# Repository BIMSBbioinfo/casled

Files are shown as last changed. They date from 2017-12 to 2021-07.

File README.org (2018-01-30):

* Layout

#+BEGIN_EXAMPLE
/firmware
/pcb
  /footprints
/schematics
  /symbols
#+END_EXAMPLE

* Software

We use the gEDA/gaf suite of tools, most importantly =gschem= for editing schematics and =pcb= for the layout of the circuit boards.

We also use the AVR toolchain to build the firmware binaries and upload them to the micro-controller.

You can get these applications through GNU Guix:

#+BEGIN_SRC bash
guix package -i geda-gaf pcb avr-toolchain@4
#+END_SRC

* Footprints and symbols

The footprints and symbols were downloaded directly from Maxim in the
=bxl= format.  gEDA software does not read the =bxl= format natively,
so it had to be converted to =.sym= (for schematic symbols) and =.fp=
(for PCB footprints).  This can be done with translate2geda [1].

[1]: https://github.com/erichVK5/translate2geda

    java translate2geda max6969awg.bxl

This results in these four files:

    21-0042B_24.fp
    21-0042B_24-L.fp
    21-0042B_24-M.fp
    MAX6969AWG.sym

I created the footprint for the XLamp LEDs from scratch according to the recommendations in the datasheet.

The =.fp= files were moved to =./pcb/footprints= and the =.sym= file to =./pcb/symbols=.

We now only need to tell =gschem= about the symbols and =pcb= about the footprints.  Run =gschem -s gschemrc cas13-led.sch= from the =pcb= directory to evaluate the code in =gschemrc= before opening up the schematic file =cas13-led.scm=.  The =gschemrc= adds the =pcb/symbols= directory to the component library.

To update the PCB after changing the schematics, run =make= from the =pcb= directory.  This runs =gsch2pcb --gnetlist-arg '-lgschemrc' project=; the =--gnetlist-arg= option must be passed to ensure that the custom symbols and footprints are found.

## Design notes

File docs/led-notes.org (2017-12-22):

This is a list of LEDs that we considered for this project before
deciding on the Cree XLamp MLESBL that is still very bright at 50mA.

* SMBB470H-1100 (epitex)
[[file:~/Downloads/SMBB470H-1100.pdf::%25PDF-1.5%0D]]
- wavelength: 470nm
- flux @350mA: 80 mW/sr or 25lm
- flux @100mA: factor 0.3 => 7.5lm

* SMBB490H-1100 (marubeni)
[[file:~/Downloads/SMBB490H-1100.pdf]]
- wavelength: 490nm
- flux @350mA: 68 mW/sr or 70lm
- flux @100mA: factor 0.35 => 24.5lm

* Cree XLamp MLEBLU-A1-0000-000U01 (groups B6+G0)
[[file:~/Downloads/XlampMLE-180564.pdf::%25PDF-1.4]]
- wavelength: 485nm
- flux @150mA: 13.9lm
- flux @100mA: 75% => 10.4lm

* Cree XLamp MLESBL-A1-0000-000U01
- wavelength: 485nm
- flux @50mA: 13.9lm!
https://eu.mouser.com/ProductDetail/Cree-Inc/MLESBL-A1-0000-000U01/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

* Lumiled Luxeon 3535L (L135-B475003500000)
[[file:~/Downloads/DS146-748694.pdf::%25PDF-1.4]]
- wavelength: 469—480nm
- flux @100mA: 11.0lm
- flux @50mA: factor 0.5 => 5.5lm
- cheap!
http://de.futureelectronics.com/de/Technologies/Product.aspx?ProductID=L135B475003500000LUMILEDS1073274&IM=0

* Lumiled Luxeon Rebel (LXML-PE01-0070)
file:~/Downloads/DS68.pdf
- flux @350mA: 76lm
- flux @100mA: unknown! Guess factor 0.2: 15.2lm
- most expensive!
http://de.futureelectronics.com/de/technologies/semiconductors/lighting-solutions/led-emitters/high-power-led-emitters-rev/Seiten/4497244-LXML-PE01-0070.aspx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

* Lumiled Luxeon Rebel (LXML-PB01-0040)
file:~/Downloads/DS68.pdf
- flux @700mA: 41lm 
- flux @100mA: factor 0.3 => 12.3lm

* Lumiled Luxeon Rebel (LXML-PB02)
file:~/Downloads/DS68.pdf
- flux @700mA: 74lm 
- flux @100mA: factor 0.2 => 14.8lm

* Cree XLamp XP-E2 (XPEBBL-L1-0000-00201)
- wavelength: 475nm
- flux @350mA: 43lm
- flux @150mA: factor 0.5 => 21.5lm
- not tested for 100mA or lower!
https://www.digikey.com/product-detail/en/cree-inc/XPEBBL-L1-0000-00201/XPEBBL-L1-0000-00201CT-ND/4111293

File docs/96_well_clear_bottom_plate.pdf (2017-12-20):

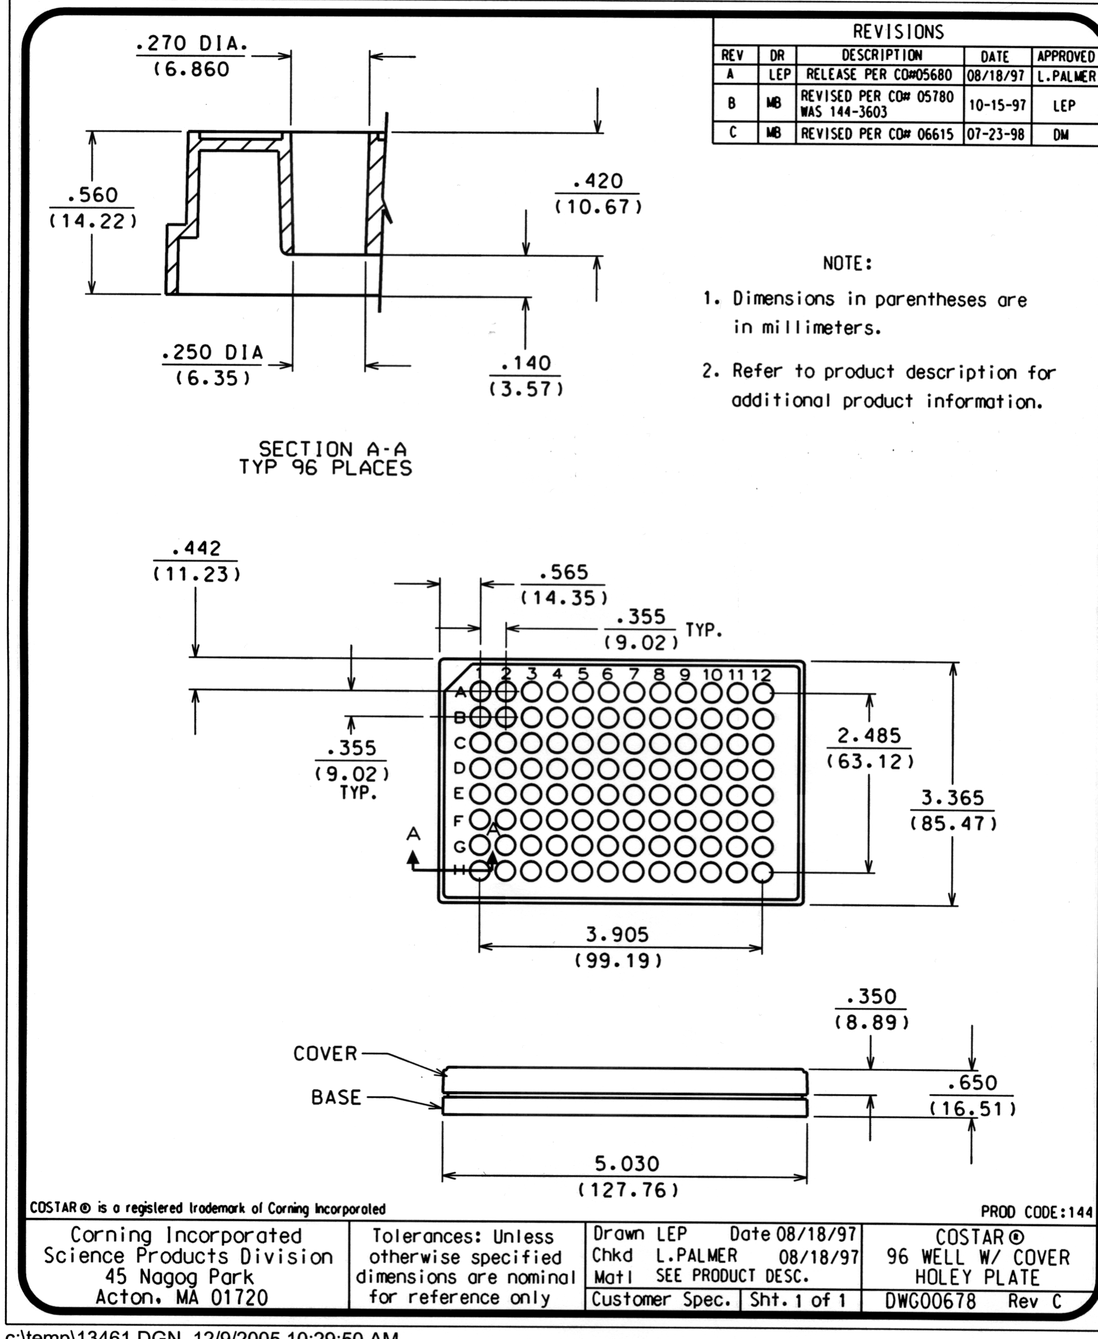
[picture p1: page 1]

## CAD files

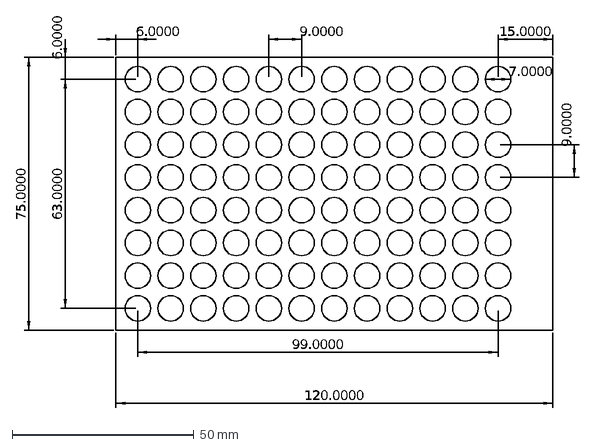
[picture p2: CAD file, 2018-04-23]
enclosure/mask.dxf
7.0000
99.0000
9.0000
6.0000
15.0000
63.0000
120.0000
75.0000

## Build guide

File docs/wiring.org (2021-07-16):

Wiring up the board is a bit challenging.

The board has a grey data cable and a black power cable.  The data
cable has three signals: red, blue, and green.  All other wires should
be tied to GND.

Connect the header with the three signals to the micro controller
board on PORTB.  The green wire should be right next to the cutout,
towards the edge of the board.  Red and blue face inward, towards the
controller chip.

The power cable has three wires:

- yellow/green for GND (at the power supply)
- blue for +5V (get from micro controller board)
- brown for +8V (or +9V if you can stand the heat), from power supply

Attach the micro controller wires to the power supply.

The lab power supply has a resistance change detector.  Disable it in
the “Setup” screen by switching “RRCd” from “YES” to “NO”.

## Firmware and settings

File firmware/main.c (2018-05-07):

#ifndef F_CPU
#warning "F_CPU was not defined, defaulting to 16MHz"
#define F_CPU 16000000UL  // must be unsigned long
#endif
#define BAUD 31250UL

#include <avr/io.h>
#include <util/setbaud.h>
#include <util/delay.h>

/* Time between program steps in milliseconds */
#define INTERVAL 1000.0

/*
Click the speaker and toggle the on-board indicator LEDs to indicate
the passing of time.
*/
#define TICK PORTD ^= 1<<PD7; PORTC++;

/* Pins used for serial interface */
#define DD_SCK    PB7 // clock (blue)
#define DD_MOSI   PB5 // data (red)
#define DDR_SPI   DDRB

/*
"Load enable" is connected to the LE pin of the LED drivers.  The
internal state of the shift registers of the driver chips is pushed to
the LED outputs on a falling edge and held as long as LE is held low
(HOLD).
*/
#define LOAD_PIN PB4 // load enable (green)
#define HOLD (PORTB &= ~(1<<LOAD_PIN))
#define LOAD (PORTB |= (1<<LOAD_PIN))


/*
There are 6 LED driver chips with 16 outputs each, so we need to
transmit 12 bytes over SPI.
*/
#define LED_BYTES 12

#include "progs.h"



#define LEDS 96

/*
Pointers to the current instruction in the program.  This is read and
updated.
*/
uint8_t* P_COUNTER[LEDS];

/*
LED state and counter.

The most significant bit is 0 for OFF and 1 for ON; the remaining bits
encode the remaining time.  When the remaining time is zero we move on
to the next instruction unless the instruction is HALT.
*/
uint8_t LED_STATE[LEDS];

/*
Pointers to LED blink programs.

This array always points to the first instruction of a program.  It is
needed in order to be able to loop back to the beginning of the
program with the LOOP instruction.  The contents of this array are
named according to the identifiers on the well plate (A-H, 1-12).

The order is all messy because the LEDs are not wired up sequentially
and we're fixing a hardware annoyance in software.  Don't judge.
*/

uint8_t* PROGRAMS[LEDS] = {
  G2, H2, E2, F2,
  G1, H1, E1, F1,

  F3, E3, H3, G3,
  F4, E4, H4, G4,

  G6, H6, E6, F6,
  G5, H5, E5, F5,

  F7, E7, H7, G7,
  F8, E8, H8, G8,

  G10, H10, E10, F10,
  G9, H9, E9, F9,

  F11, E11, H11, G11,
  F12, E12, H12, G12,

  B2, A2, D2, C2,
  B1, A1, D1, C1,

  C3, D3, A3, B3,
  C4, D4, A4, B4,

  B6, A6, D6, C6,
  B5, A5, D5, C5,

  C7, D7, A7, B7,
  C8, D8, A8, B8,

  B10, A10, D10, C10,
  B9, A9, D9, C9,

  C11, D11, A11, BROKEN,
  C12, D12, A12, BROKEN
};

/* Initialize SPI interface. */
void spi_init () {
  // Latch, MOSI, and SCK are outputs, all others are inputs
  DDR_SPI = (1<<LOAD_PIN)|(1<<DD_MOSI)|(1<<DD_SCK);
  // Enable SPI as Master, clock rate is fck/128
  //SPCR = (1<<SPE)|(1<<MSTR)|(1<<SPI2X)|(0<<SPR1)|(0<<SPR0);
  SPCR = (1<<SPE)|(1<<MSTR)|(0<<SPI2X)|(1<<SPR1)|(1<<SPR0);
}

/* Send a byte over SPI and wait for completion. */
void spi_transmit (uint8_t data) {
  SPDR = data;
  // Wait for transmission completion
  while (!(SPSR & (1<<SPIF)));
}

/*
Evaluate the current instruction for all LED programs.

This either leads to a delay counter to be decremented or the next
instruction to be selected.
*/
void prog_eval () {
  // LED states to be sent over serial connection.
  uint8_t bytes[LED_BYTES] = {0};

  for (uint8_t i=0; i < LEDS; i++)
    {
      /*
        Are we still waiting for an ON/OFF instruction to be
        completed?
      */
      if (LED_STATE[i] & 0x7F) {
        // Yes, so just count down.
        LED_STATE[i]--;
      } else {
        /*
          Reset and evaluate the next instruction on LOOP.  The first
          instruction cannot be LOOP.
        */
        if (LOOP == *(P_COUNTER[i]))
          P_COUNTER[i] = PROGRAMS[i];

        if (HALT != *(P_COUNTER[i])) {
          // initialize count down
          LED_STATE[i] = *(P_COUNTER[i]);
          // advance program
          P_COUNTER[i]++;
        }
      }

      /* Set LED on or off in byte message array */
      uint8_t new_state = (LED_STATE[i] >> 7);
      if (new_state) {
        // set bit
        bytes[i / 8] |= (1 << (i % 8));
      } else {
        // clear bit
        bytes[i / 8] &= ~(1 << (i % 8));
      }
    }

  /* Transmit new state for all LEDs */
  for (uint8_t n = 0; n < LED_BYTES; n++)
    spi_transmit (bytes[n]);
  LOAD; _delay_ms(10.0); HOLD;
  TICK;
}

void init (void) {
  spi_init ();
  DDRD = 0xFF;  // all outputs (for speaker and "load enable")
  DDRC = 0xFF;  // all outputs
  PORTC = 0x00; // all activity indicator LEDs on

  /* Turn all external LEDs off initially */
  for (uint8_t n = 0; n < LED_BYTES; n++)
    spi_transmit (0x00);
  LOAD; _delay_ms(1000.0); HOLD;

  /* Initialize LED programs and associated state */
  for (uint8_t i = 0; i < LEDS; i++)
    {
      P_COUNTER[i] = PROGRAMS[i];
      LED_STATE[i] = 0x00;
    }
}

int main (void) {
  init ();

  uint8_t p = 0;
  while (p < 40)
    {
      TCCR2 = (1<<FOC2)|(1<<WGM21)|(1<<COM20);
      //TCNT2 = 0;
      _delay_ms(20.0);
      OCR2 = p++;
      TCCR2 |= (1<<CS22)|(1<<CS21)|(1<<CS20);
      _delay_ms(9.0);
    }
  TCCR2 = 0;

  _delay_ms(1000.0);
  while (1) {
    prog_eval ();
    _delay_ms(INTERVAL);
  }

  // This will never happen.
  return 0;
}

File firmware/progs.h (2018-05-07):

#include <avr/io.h>
#include <util/delay.h>

/* LED program instructions */
#define LOOP 0x7F
#define HALT 0xFF

/* Instructions to turn the LED on/off for 1 to 127 units. */
#define LED_ON(n)  ((0x80 | ((n) - 1)))
#define LED_OFF(n) ((0x7F & ((n) - 1)))

/*
NOTE: programs cannot begin with LOOP.  All programs must end with
either LOOP or HALT.
*/

/* This program ensures that the LED stays off. */
uint8_t progOff[] = { LED_OFF(10), LOOP };

/* This program ensures that the LED stays lit. */
uint8_t progOn[]  = { LED_ON(1), HALT };

/* This program lets an LED blink 50/50. */
uint8_t progBlink[] = { LED_ON(1), LED_OFF(1), LOOP };

/* This program lets an LED blink 50/50, but starts in the Off state. */
uint8_t progBlinkOff[] = { LED_OFF(1), LED_ON(1), LOOP };

#define ON_TIME 10
#define OFF_TIME 20

/* Constant blink for Magnet photo dimer */
uint8_t progMagnetBlink[] = { LED_ON(ON_TIME), LED_OFF(OFF_TIME), LOOP };

/* Blink, then lock ON for Magnet photo dimer */
uint8_t progMagnetBlinkLockOn[] = {
  LED_ON(3),   /* 1 */
  LED_OFF(7),
  LED_ON(3),   /* 2 */
  LED_OFF(7),
  LED_ON(3),   /* 3 */
  LED_OFF(7),
  LED_ON(3),   /* 4 */
  LED_OFF(7),
  LED_ON(3),   /* 5 */
  LED_OFF(7),
  LED_ON(3),   /* 6 */
  LED_OFF(7),
  LED_ON(3),   /* 7 */
  LED_OFF(7),
  LED_ON(3),   /* 8 */
  LED_OFF(7),
  LED_ON(3),   /* 9 */
  LED_OFF(7),
  LED_ON(3),   /* 10 */
  LED_OFF(7),
  LED_ON(3),   /* 11 */
  LED_OFF(7),
  LED_ON(3),   /* 12 */
  LED_OFF(7),
  LED_ON(3),   /* 13 */
  LED_OFF(7),
  LED_ON(3),   /* 14 */
  LED_OFF(7),
  LED_ON(3),   /* 15 */
  LED_OFF(7),
  LED_ON(3),   /* 16 */
  LED_OFF(7),
  LED_ON(3),   /* 17 */
  LED_OFF(7),
  LED_ON(3),   /* 18 */
  LED_OFF(7),
  LED_ON(3),   /* 19 */
  LED_OFF(7),
  LED_ON(3),   /* 20 */
  LED_OFF(7),

  LED_ON(120),
  LOOP
};

/* Blink, then lock OFF for Magnet photo dimer */
uint8_t progMagnetBlinkLockOff[] = {
  LED_ON(3),   /* 1 */
  LED_OFF(7),
  LED_ON(3),   /* 2 */
  LED_OFF(7),
  LED_ON(3),   /* 3 */
  LED_OFF(7),
  LED_ON(3),   /* 4 */
  LED_OFF(7),
  LED_ON(3),   /* 5 */
  LED_OFF(7),
  LED_ON(3),   /* 6 */
  LED_OFF(7),
  LED_ON(3),   /* 7 */
  LED_OFF(7),
  LED_ON(3),   /* 8 */
  LED_OFF(7),
  LED_ON(3),   /* 9 */
  LED_OFF(7),
  LED_ON(3),   /* 10 */
  LED_OFF(7),
  LED_ON(3),   /* 11 */
  LED_OFF(7),
  LED_ON(3),   /* 12 */
  LED_OFF(7),
  LED_ON(3),   /* 13 */
  LED_OFF(7),
  LED_ON(3),   /* 14 */
  LED_OFF(7),
  LED_ON(3),   /* 15 */
  LED_OFF(7),
  LED_ON(3),   /* 16 */
  LED_OFF(7),
  LED_ON(3),   /* 17 */
  LED_OFF(7),
  LED_ON(3),   /* 18 */
  LED_OFF(7),
  LED_ON(3),   /* 19 */
  LED_OFF(7),
  LED_ON(3),   /* 20 */
  LED_OFF(7),

  LED_OFF(120),
  LOOP
};


/*
Toggle LED on/off for three times, then leave off for 10 mins, then
restart the program.
*/
uint8_t progExample[] = {
  LED_ON(1),
  LED_OFF(1),
  LED_ON(1),
  LED_OFF(1),
  LED_ON(1),
  LED_OFF(127),
  LED_OFF(127),
  LED_OFF(127),
  LED_OFF(127),
  LED_OFF(92),  // 10 mins off
  LOOP // programs MUST end on either LOOP or HALT
};




#define BROKEN progOff

#define A1  progOff
#define A2  progOff
#define A3  progOff
#define A4  progOff
#define A5  progOff
#define A6  progOff
#define A7  progMagnetBlink
#define A8  progMagnetBlink
#define A9  progMagnetBlink
#define A10 progMagnetBlink
#define A11 progMagnetBlink
#define A12 progMagnetBlink

#define B1  progOff
#define B2  progOff
#define B3  progOff
#define B4  progOff
#define B5  BROKEN
#define B6  progOff
#define B7  progMagnetBlink
#define B8  progMagnetBlink
#define B9  progMagnetBlink
#define B10 BROKEN
#define B11 BROKEN
#define B12 BROKEN

#define C1  progOff
#define C2  progOff
#define C3  progOff
#define C4  BROKEN
#define C5  progOff
#define C6  progOff
#define C7  progMagnetBlink
#define C8  progMagnetBlink
#define C9  progMagnetBlink
#define C10 progOff
#define C11 progOff
#define C12 progOff

#define D1  progOff
#define D2  progOff
#define D3  BROKEN
#define D4  progOff
#define D5  BROKEN
#define D6  progOff //BROKEN?
#define D7  progOff
#define D8  progOff
#define D9  progOff
#define D10 BROKEN
#define D11 BROKEN
#define D12 progMagnetBlink

#define E1  BROKEN
#define E2  progOff
#define E3  progOff
#define E4  progOn
#define E5  progOn
#define E6  progOn
#define E7  progOff
#define E8  progOff
#define E9  progOff
#define E10 progMagnetBlink
#define E11 progMagnetBlink
#define E12 progMagnetBlink

#define F1  progOff
#define F2  progOff
#define F3  progOff
#define F4  progOn
#define F5  progOn
#define F6  progOn
#define F7  progOff
#define F8  progOff
#define F9  progOff
#define F10 progMagnetBlink
#define F11 progMagnetBlink
#define F12 progMagnetBlink

#define G1  progOff
#define G2  progOff
#define G3  BROKEN
#define G4  progOn
#define G5  progOn
#define G6  progOn
#define G7  progOff
#define G8  progOff
#define G9  progOff
#define G10 progMagnetBlink
#define G11 progMagnetBlink
#define G12 progMagnetBlink

#define H1  progOff
#define H2  progOff
#define H3  progOff
#define H4  progOn
#define H5  progOn
#define H6  progOn
#define H7  progOff
#define H8  progOff
#define H9  progOff
#define H10 progMagnetBlink
#define H11 progMagnetBlink
#define H12 BROKEN

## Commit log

2017-11-04 Initial commit.
    [cas13-led.sch]
2017-12-15 pcb: Add simple footprint for XLamp LED.
    * pcb/footprints/xlamp.fp: New file.
2017-12-19 schematics: Add xlamp footprints.
    [cas13-led.sch]
2017-12-19 pcb: Tell gsch2pcb where to find footprints.
2017-12-19 Add note about xlamp footprint.
2017-12-19 pcb: Roughly place LEDs.
2017-12-20 pcb: Place and wire all LEDs.
2017-12-20 schematics: Double the number of LEDs.
    [cas13-led.sch]
2017-12-20 pcb: Place all LEDs.
2017-12-20 Add well plate documentation.
2017-12-20 pcb: Align PCB edges with well plate edges.
2017-12-22 pcb: Roughly wire up LEDs to MAX6969.
    [cas13-led.sch]
2017-12-22 docs: Add LED notes.
    * docs/led-notes.org: New file.
2017-12-22 pcb: Add current setting resistors.
    [cas13-led.sch]
2017-12-22 pcb: Connect LEDs to common Vcc, not common GND.
    [cas13-led.sch]
2017-12-22 pcb: Update "update" target.
2017-12-22 pcb: Rearrange LED connections for U1.
    [cas13-led.sch]
2017-12-22 pcb: Rearrange LED connections for U3 and U5.
    [cas13-led.sch]
2018-01-14 pcb: Add support caps for all ICs.
    [cas13-led.sch]
2018-01-14 pcb: Add caps to PCB and draft wires.
2018-01-15 Tie OE to GND.
    [cas13-led.sch]
2018-01-15 Remove driver circuits from LED PCB.
2018-01-16 pcb: Add script to generate pin header footprint.
2018-01-16 pcb: Add footprint for 2x32 surface mount pin header.
2018-01-16 pcb: Add symbol for 2x32 pin header.
2018-01-16 pcb: Split schematic.
    [cas13-led.sch, drivers.sch]
2018-01-16 pcb: Split PCBs.
2018-01-16 pcb: Fix pin header footprint.
2018-01-16 pcb: Add two pin headers.
    [cas13-led.sch]
2018-01-16 pcb: Fix duplicate pin in header symbol 3 -> 23.
2018-01-16 pcb: Generate alternating pins.
2018-01-16 pcb: Use alternating pin header.
2018-01-17 pcb: Wire up top header.
    [cas13-led.sch]
2018-01-18 pcb: Connect both headers.
    [cas13-led.sch]
2018-01-21 pcb: Connect all traces.
2018-01-21 pcb: Carry +5V, GND, and LED+ on header.
    [cas13-led.sch]
2018-01-21 pcb: Add more text to top silk.
2018-01-21 pcb: Shrink board.
2018-01-29 pcb: Clear solder mask around LED pads.
2018-01-29 pcb: Apply LED footprint changes to PCB.
2018-01-29 pcb: Increase text size.
2018-01-29 pcb: Clear solder mask around pin header pins.
2018-01-29 pcb: Apply pin header footprint changes to PCB.
2018-01-30 pcb: Add generator for pin header holes.
2018-01-30 pcb: Add footprint for DIL pin header.
2018-01-30 pcb: Add pin headers to drivers PCB.
    [drivers.sch]
2018-01-30 pcb: Begin layouting drivers PCB.
2018-01-30 pcb: Fix connection of U5-8 to CONN1-45.
    [drivers.sch]
2018-02-13 pcb: Use larger resistors.
    [drivers.sch]
2018-02-13 pcb: Hide components that are the same on the two driver PCBs.
    [drivers.sch]
2018-02-13 pcb: Connect data of U1->U3->U5, then U5->U2->U4->U6.
    [drivers.sch]
2018-02-13 pcb: Update driver PCB layout.
2018-02-13 pcb: Use correct footprint for connectors.
    [drivers.sch]
2018-02-13 pcb: Finish layout of driver boards.
2018-02-13 pcb: Almost forgot to add power pins!
2018-02-14 pcb: Remove some annoying stains and drops.
2018-04-03 Add enclosure design for laser cutting.
2018-04-23 enclosure: Add drawing of LED mask.
    [mask.dxf]
2018-04-30 firmware: Don't lock on transmission error.
    [main.c]
2018-05-01 firmware: Move LED programs to separate file.
2018-05-01 firmware: Move LE to PD0.
    This avoids accidental problems when using SPI features that are
    available on PORTB.
    [main.c]
2018-05-01 firmware: Slow down SPI rate. It's safer.
2018-05-07 firmware: Use Magnet programmes.
    This is the programming used for the first experiment with this
    device. Four clusters: constant off, constant on, blink, blink.
2019-01-11 docs: Document board wiring.
    * docs/wiring.org: New file.
2021-07-16 Clarify wiring.
